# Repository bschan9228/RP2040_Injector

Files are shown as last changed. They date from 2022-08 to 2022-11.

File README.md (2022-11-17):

The RP2040 Injector is a 4-layer PCB. It is essentially used as a keystroke injector. I sourced components, made the schematics and designed the PCB, and hand soldered the components onto a two-sided PCB. It utilizes an RP2040, voltage regulator, a USB Type-A connector.

A6C2860C-CAA3-4934-8C7F-B25708A417A8

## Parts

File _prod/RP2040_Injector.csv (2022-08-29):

Comment | Designator | Footprint | LCSC Part #
100n Unpolarized capacitor | C1,C2,C3,C4,C5,C6,C7,C9,C10,C16 | C_0402_1005Metric
1u Unpolarized capacitor | C8,C11 | C_0402_1005Metric
10u Unpolarized capacitor | C12,C13 | C_0805_2012Metric
20p Unpolarized capacitor | C14,C15 | C_0402_1005Metric
LED Light emitting diode | D1 | LED_0603_1608Metric
0805L050WR Resettable fuse, polymeric positive temperature coefficient | F1 | Fuse_0805_2012Metric
12MHz Four pin crystal, GND on pins 2 and 4 | HSE1 | Crystal_SMD_SeikoEpson_FA238-4Pin_3.2x2.5mm
USB-A | J1 | MOLEX_48037-0001
Conn_01x02 Generic connector, single row, 01x02, script generated (kicad-library-utils/schlib/autogen/connector/) | J2 | PinHeader_1x02_P2.00mm_Vertical
2k2 Resistor | R1 | R_0402_1005Metric
1k Resistor | R2,R5 | R_0402_1005Metric
27 Resistor | R3,R4 | R_0402_1005Metric
NCP1117-3.3_SOT223 1A Low drop-out regulator, Fixed Output 3.3V, SOT-223 | U1 | SOT-223-3_TabPin2
RP2040 | U2 | QFN40P700X700X90-57N
W25Q128JVS 128Mb Serial Flash Memory, Standard/Dual/Quad SPI, SOIC-8 | U3 | SOIC-8_5.23x5.23mm_P1.27mm

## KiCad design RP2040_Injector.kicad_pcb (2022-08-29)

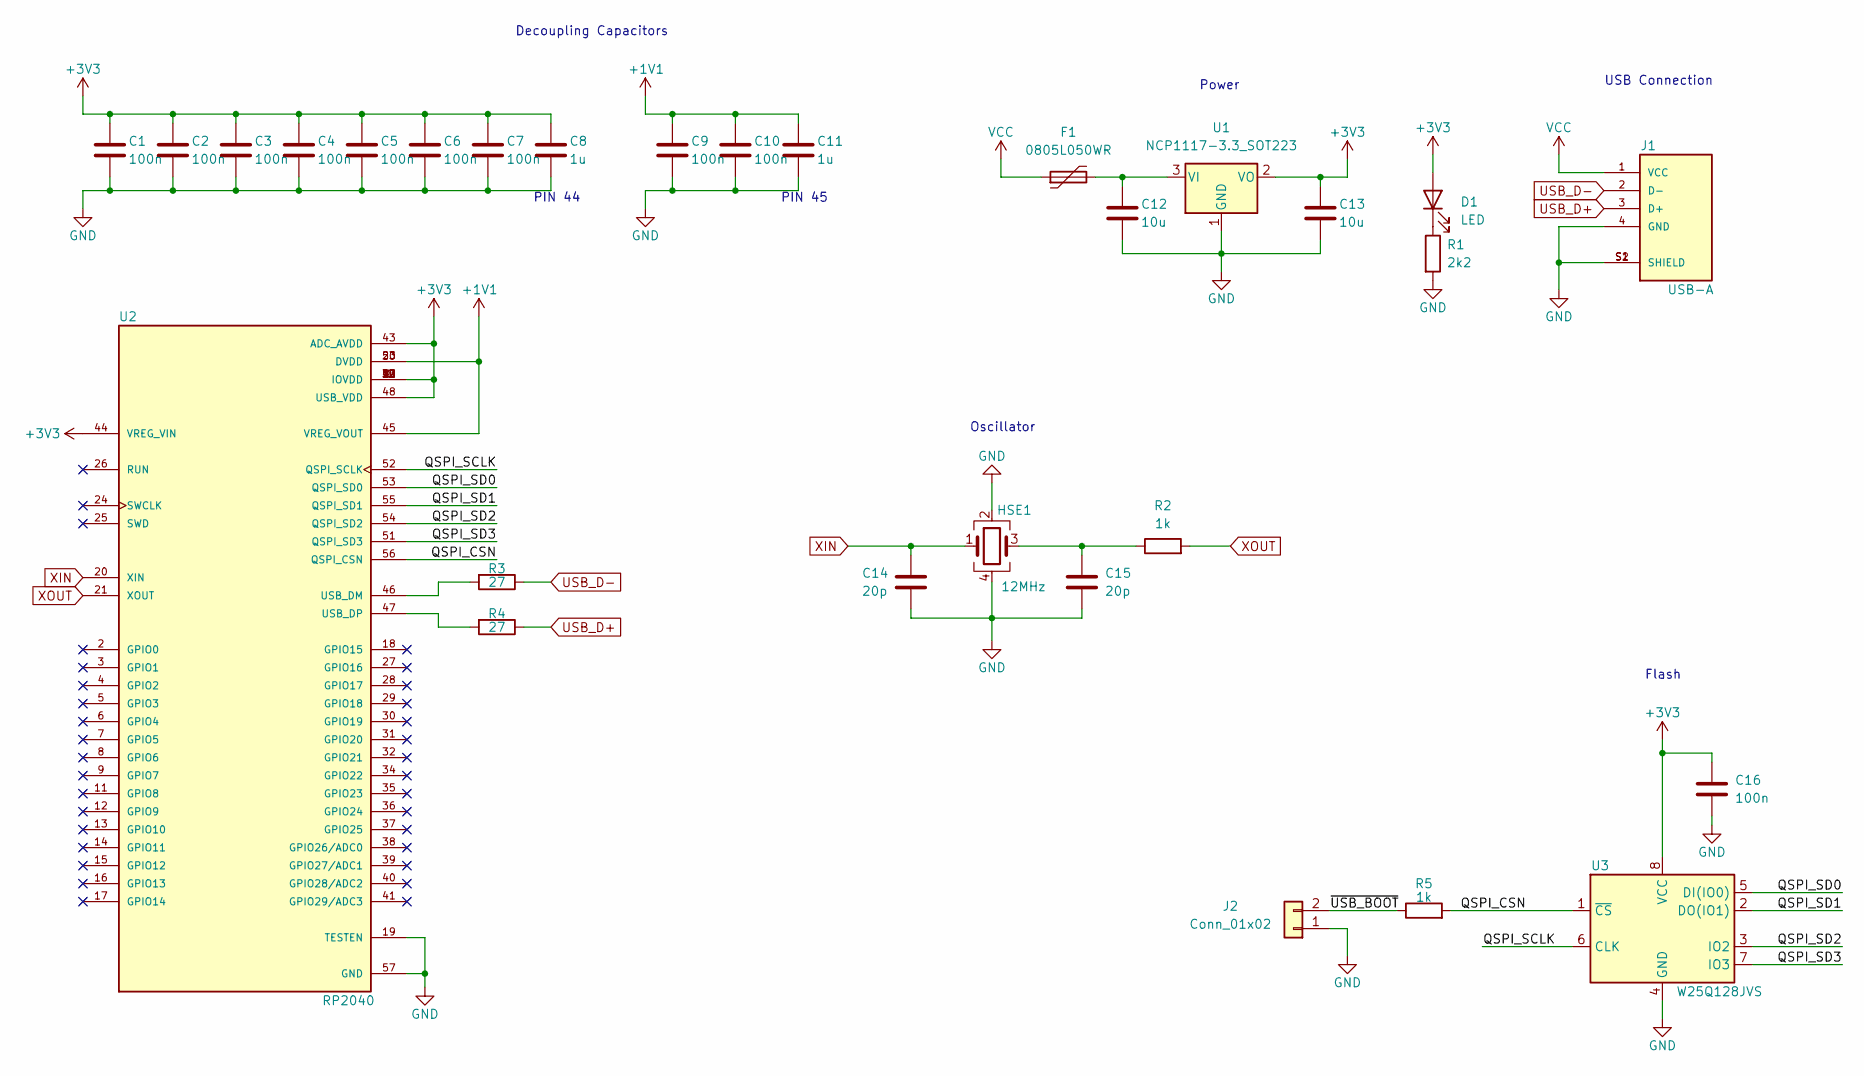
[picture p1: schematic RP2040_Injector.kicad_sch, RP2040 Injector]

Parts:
C1, C2, C3, C4, C5, C6, C7, C9, C10, C16: 100n; C_0402_1005Metric
C8, C11: 1u; C_0402_1005Metric
C12, C13: 10u; C_0805_2012Metric
C14, C15: 20p; C_0402_1005Metric
D1: LED; LED_0603_1608Metric
F1: 0805L050WR; Fuse_0805_2012Metric
HSE1: 12MHz; Crystal_SMD_SeikoEpson_FA238-4Pin_3.2x2.5mm
J1: USB-A; MOLEX_48037-0001; PARTREV D
J2: Conn_01x02; PinHeader_1x02_P2.00mm_Vertical
R1: 2k2; R_0402_1005Metric
R2, R5: 1k; R_0402_1005Metric
R3, R4: 27; R_0402_1005Metric
U1: NCP1117-3.3_SOT223; SOT-223-3_TabPin2
U2: RP2040; QFN40P700X700X90-57N; PARTREV 1.6.1
U3: W25Q128JVS; SOIC-8_5.23x5.23mm_P1.27mm

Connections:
+1V1: C9.1, C10.1, C11.1, U2.23 (DVDD), U2.45 (VREG_VOUT), U2.50 (DVDD)
+3V3: C1.1, C2.1, C3.1, C4.1, C5.1, C6.1, C7.1, C8.1, C13.1, C16.1, D1.2 (A), U1.2 (VO), U2.1 (IOVDD), U2.10 (IOVDD), U2.22 (IOVDD), U2.33 (IOVDD), U2.42 (IOVDD), U2.43 (ADC_AVDD), U2.44 (VREG_VIN), U2.48 (USB_VDD), U2.49 (IOVDD), U3.8 (VCC)
/QSPI_CSN: R5.2, U2.56 (QSPI_CSN), U3.1 (~CS)
/QSPI_SCLK: U2.52 (QSPI_SCLK), U3.6 (CLK)
/QSPI_SD0: U2.53 (QSPI_SD0), U3.5 (DI(IO0))
/QSPI_SD1: U2.55 (QSPI_SD1), U3.2 (DO(IO1))
/QSPI_SD2: U2.54 (QSPI_SD2), U3.3 (IO2)
/QSPI_SD3: U2.51 (QSPI_SD3), U3.7 (IO3)
/~USB_BOOT: J2.2, R5.1
GND: C1.2, C2.2, C3.2, C4.2, C5.2, C6.2, C7.2, C8.2, C9.2, C10.2, C11.2, C12.2, C13.2, C14.2, C15.2, C16.2, HSE1.2, HSE1.4, J1.4 (GND), J1.S1 (SHIELD), J1.S2 (SHIELD), J2.1, R1.2, U1.1 (GND), U2.19 (TESTEN), U2.57 (GND), U3.4 (GND)
unnamed: C12.1, F1.2, U1.3 (VI)
unnamed: C15.1, HSE1.3, R2.1
unnamed: D1.1 (K), R1.1
unnamed: R3.2, U2.46 (USB_DM)
unnamed: R4.2, U2.47 (USB_DP)
USB_D+: J1.3 (D+), R4.1
USB_D-: J1.2 (D-), R3.1
VCC: F1.1, J1.1 (VCC)
XIN: C14.1, HSE1.1, U2.20 (XIN)
XOUT: R2.2, U2.21 (XOUT)

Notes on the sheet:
PIN 45
Oscillator
PIN 44
Decoupling Capacitors
Flash
Power
USB Connection

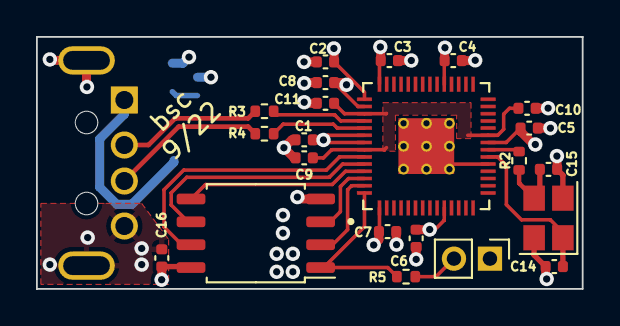
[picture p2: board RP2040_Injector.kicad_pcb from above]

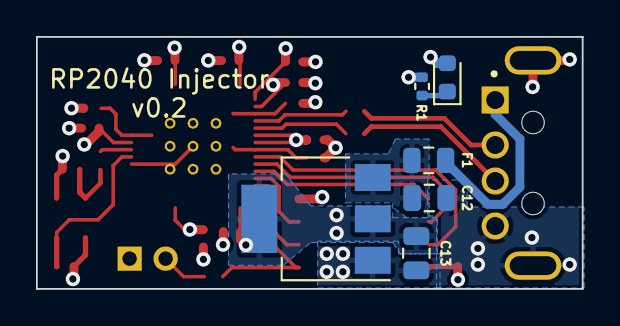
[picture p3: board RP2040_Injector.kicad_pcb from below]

Board: 4 copper layers, 30.3 x 14.0 mm, 29 parts (7 on the bottom side), 20 nets.

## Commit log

2022-08-26 Finished v0.1 PCB wiring
    [RP2040_Injector-B_Cu.gbr, RP2040_Injector-B_Mask.gbr, RP2040_Injector-B_Paste.gbr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]
2022-08-26 Finished PCB wiring
    [RP2040_Injector.csv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]
2022-08-26 Finalized v0.1 design
    [RP2040_Injector-B_Cu.gbr, RP2040_Injector-B_Mask.gbr, RP2040_Injector-B_Paste.gbr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]
2022-08-28 Started v0.2
    [RP2040_Injector.kicad_pcb, RP2040_Injector.kicad_sch]
2022-08-28 Finished wiring
    [RP2040_Injector.kicad_pcb]
2022-08-29 Completed v0.2
    [RP2040_Injector-B_Cu.gbr, RP2040_Injector-B_Mask.gbr, RP2040_Injector-B_Paste.gbr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]
